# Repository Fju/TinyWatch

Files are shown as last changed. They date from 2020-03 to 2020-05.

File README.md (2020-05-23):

# AVRist-watch

A DIY project that involves an ATmega328p that controlls a small monochrome OLED display powered by a chargable LiPo battery - or in short: a digital wrist watch.

## Features

- **Real Time Clock**: An IC keeps track of the current date and time even if the display and microcontroller is turned off.

- **Li-Po battery management**: The board features a charge controller that allows charging the battery via Micro USB. Another IC protects the battery from over-charging and over-discharging.

- **OLED-Display**: A monochrome 128x64 pixel OLED display is used to show the current time.

- **Energy Efficiency**: After displaying the current time for a couple of seconds the display turns off and the microcontroller enters a sleep mode. This saves battery power.

## Images

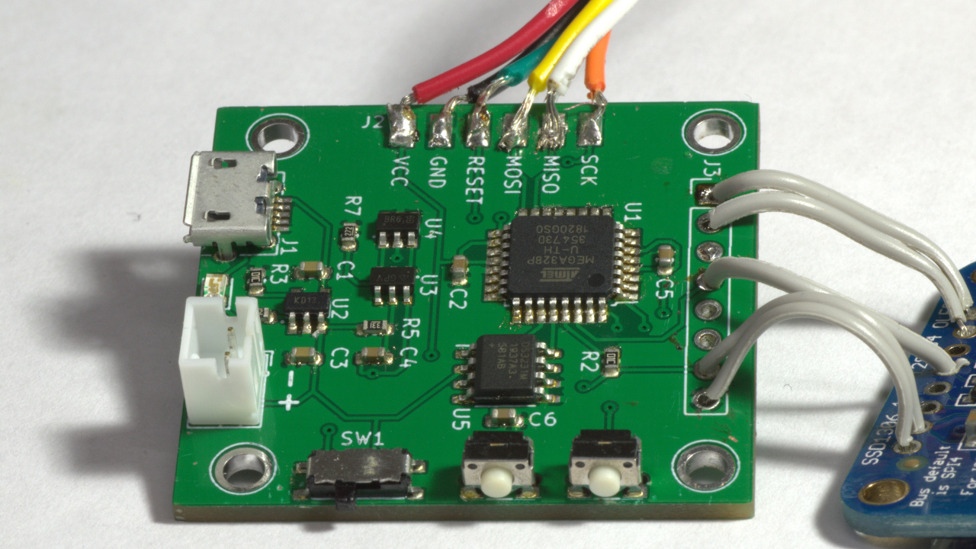
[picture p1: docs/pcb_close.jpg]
PCB up close


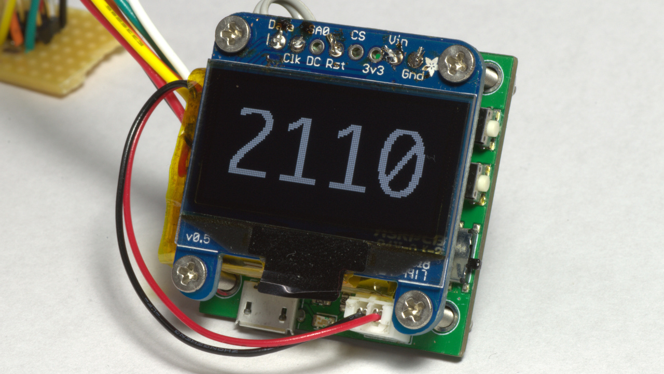
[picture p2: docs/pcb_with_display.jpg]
PCB with OLED display on top


## Schematic

Schematic

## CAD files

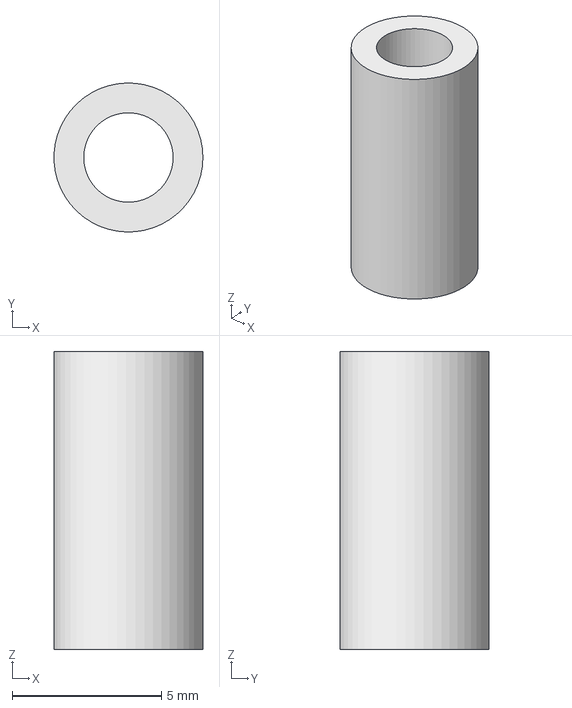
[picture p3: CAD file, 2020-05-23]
parts/mounts.FCStd
5.00 x 5.00 x 10.0 mm

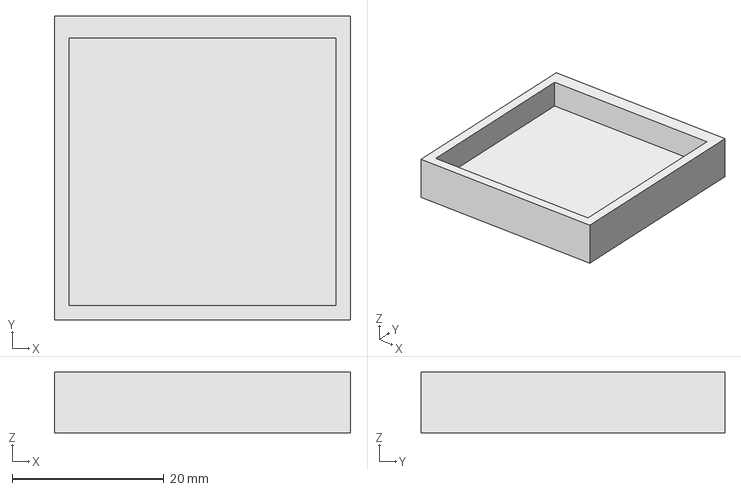
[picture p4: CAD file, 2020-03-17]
parts/case.FCStd
39.0 x 40.0 x 8.00 mm

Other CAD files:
parts/mounts.stl

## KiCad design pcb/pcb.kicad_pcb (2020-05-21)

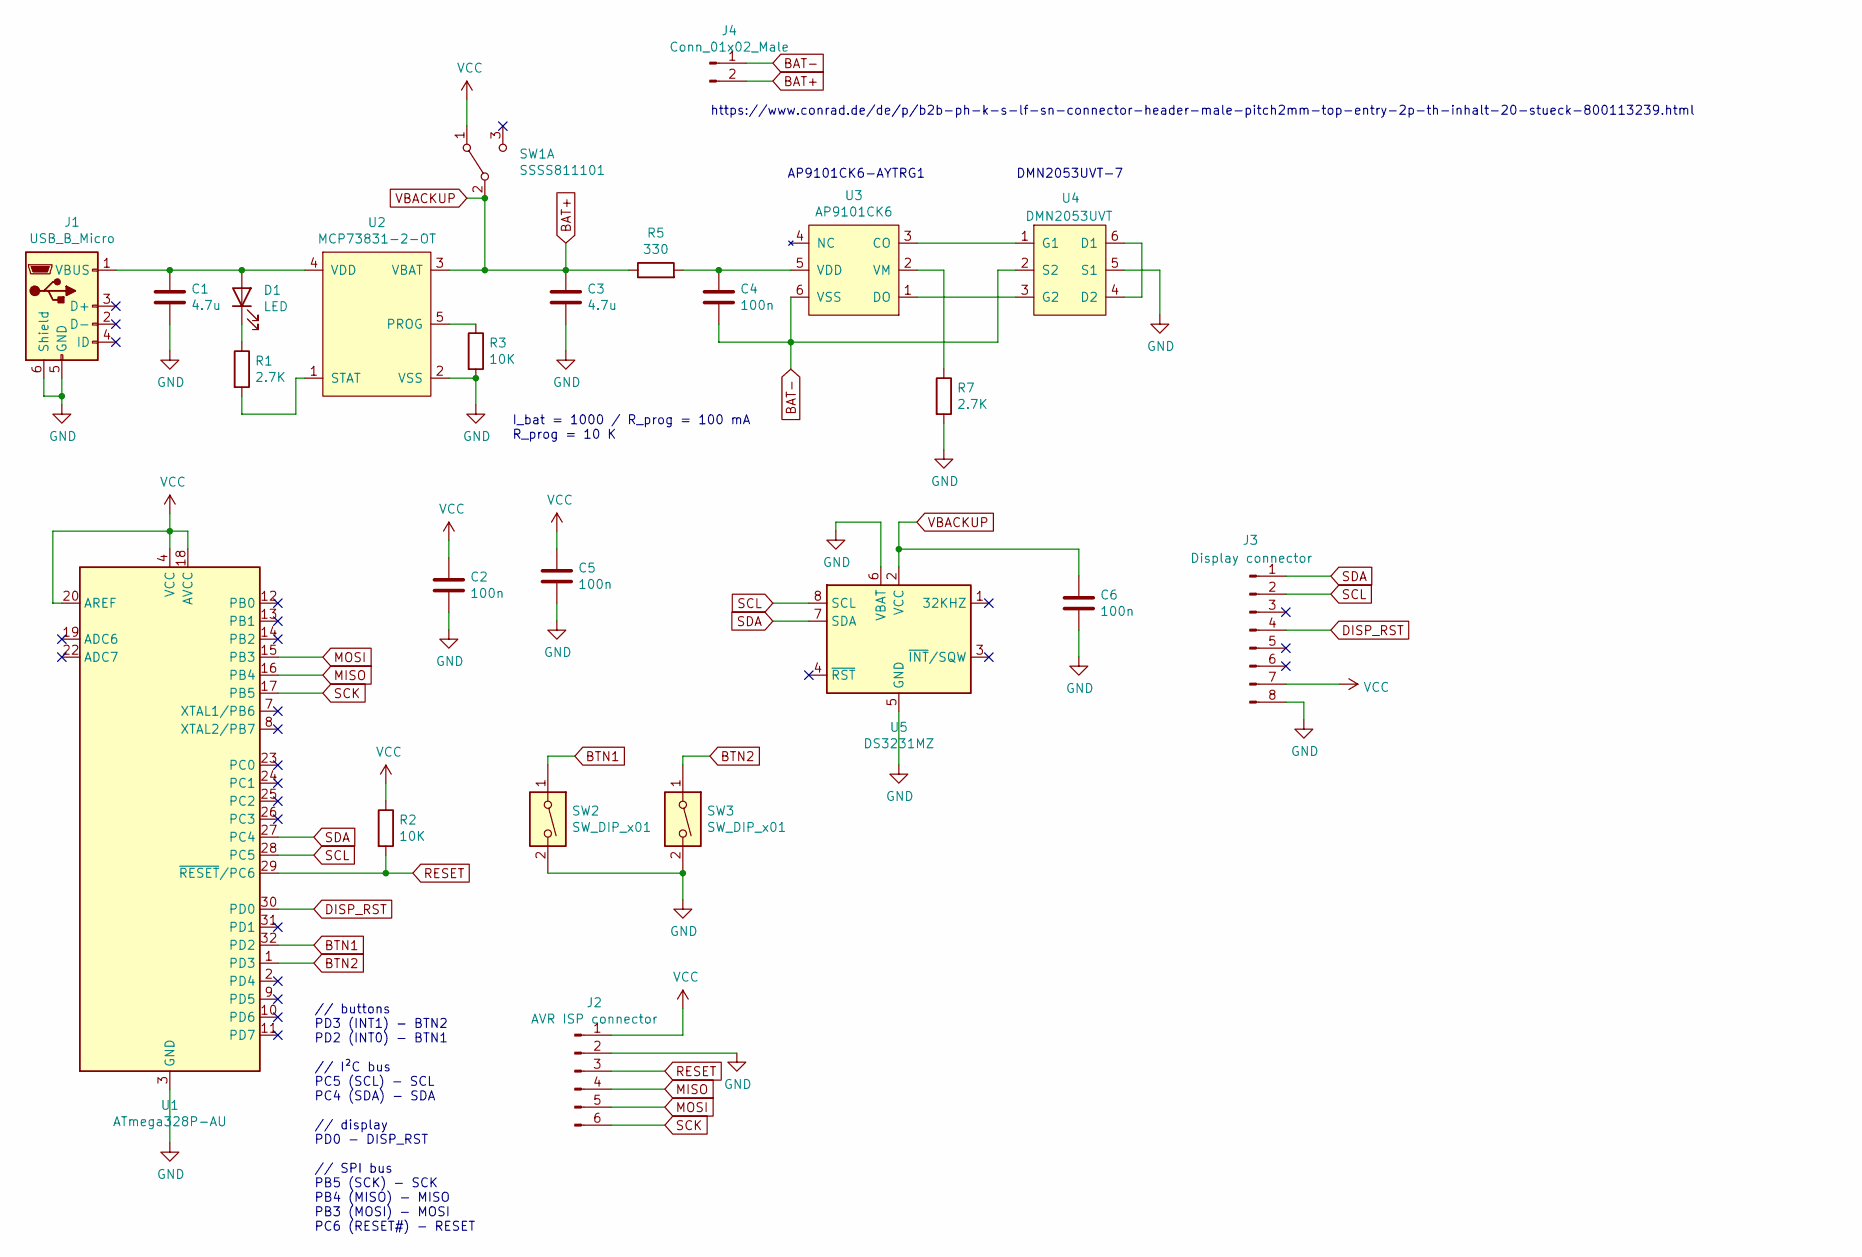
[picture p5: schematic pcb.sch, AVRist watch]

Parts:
C1, C3: 4.7u; C_0603_1608Metric
C2, C4, C5, C6: 100n; C_0603_1608Metric
D1: LED; LED_0805_2012Metric
J1: USB_B_Micro; USB_B_micro
J2: AVR ISP connector; CONN_AVR_ISP_SMD
J3: Display connector; PinHeader_1x08_P2.54mm_Vertical
J4: Conn_01x02_Male; JST_PH_B2B-PH-K_1x02_P2.00mm_Vertical
R1, R7: 2.7K; R_0603_1608Metric
R2, R3: 10K; R_0603_1608Metric
R5: 330; R_0603_1608Metric
SW1: SSSS811101
SW2, SW3: SW_DIP_x01; TL3340_SMT
U1: ATmega328P-AU; TQFP-32_7x7mm_P0.8mm
U2: MCP73831-2-OT; MCP73831_SOT-23
U3: AP9101CK6; AP9101C_SOT-25
U4: DMN2053UVT; DMN2053UVT_TSOT-26
U5: DS3231MZ; SOIC-8_3.9x4.9mm_P1.27mm

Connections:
BAT+: C3.1, C6.1, J4.2, R5.1, SW1.2 (B), U2.3 (VBAT), U5.2 (VCC)
BAT-: C4.2, J4.1, U3.6 (VSS), U4.2 (S2)
BTN1: SW2.1, U1.32 (PD2)
BTN2: SW3.1, U1.1 (PD3)
DISP_RST: J3.4, U1.30 (PD0)
GND: C1.2, C2.2, C3.2, C5.2, C6.2, J1.5 (GND), J1.6 (Shield), J2.2, J3.8, R3.2, R7.2, SW2.2, SW3.2, U1.3 (GND), U1.5 (GND), U1.21 (GND), U2.2 (VSS), U4.5 (S1), U5.5 (GND), U5.6 (VBAT)
MISO: J2.4, U1.16 (PB4)
MOSI: J2.5, U1.15 (PB3)
unnamed: C1.1, D1.2 (A), J1.1 (VBUS), U2.4 (VDD)
unnamed: C4.1, R5.2, U3.5 (VDD)
unnamed: D1.1 (K), R1.1
unnamed: R1.2, U2.1 (STAT)
unnamed: R3.1, U2.5 (PROG)
unnamed: R7.1, U3.2 (VM)
unnamed: U3.1 (DO), U4.3 (G2)
unnamed: U3.3 (CO), U4.1 (G1)
unnamed: U4.4 (D2), U4.6 (D1)
RESET: J2.3, R2.2, U1.29 (~RESET~/PC6)
SCK: J2.6, U1.17 (PB5)
SCL: J3.2, U1.28 (PC5), U5.8 (SCL)
SDA: J3.1, U1.27 (PC4), U5.7 (SDA)
VCC: C2.1, C5.1, J2.1, J3.7, R2.1, SW1.1 (A), U1.4 (VCC), U1.6 (VCC), U1.18 (AVCC), U1.20 (AREF)

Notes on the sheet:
I_bat = 1000 / R_prog = 100 mA R_prog = 10 K
// buttons PD3 (INT1) - BTN2 PD2 (INT0) - BTN1 // I²C bus PC5 (SCL) - SCL PC4 (SDA) - SDA // display PD0 - DISP_RST // SPI bus PB5 (SCK) - SCK PB4 (MISO) - MISO PB3 (MOSI) - MOSI PC6 (RESET#) - RESET
AP9101CK6-AYTRG1
DMN2053UVT-7
https://www.conrad.de/de/p/b2b-ph-k-s-lf-sn-connector-header-male-pitch2mm-top-entry-2p-th-inhalt-20-stueck-800113239.html

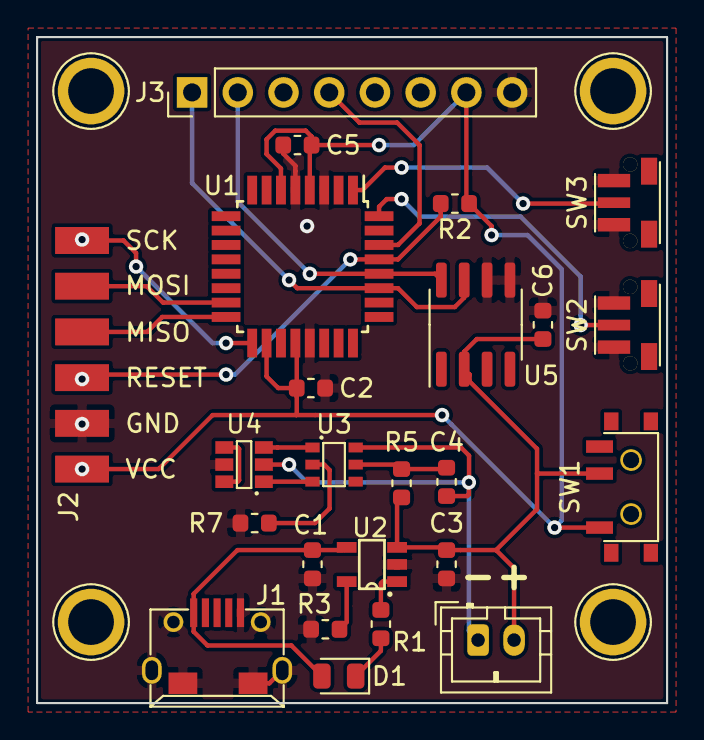
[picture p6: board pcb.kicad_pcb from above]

Board: 2 copper layers, 35.0 x 37.0 mm, 24 parts (0 on the bottom side), 22 nets.

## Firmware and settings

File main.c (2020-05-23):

#include <avr/io.h>
#include <avr/power.h>
#include <avr/sleep.h>
#include <avr/interrupt.h>

#include "screen.h"
#include "i2c_master.h"
#include "fonts.h"
#include "clock.h"

#include <util/delay.h>

enum state_t {
	S_TIME,			// display time
	S_MENU_TIME,	// set time (hours and minutes)
	S_MENU_DATE,	// set date (day and month)
	S_MENU_YEAR		// set year
};

int main() {
	// set all I/O to outputs to save some energy, except the following:
	// INT0 (PD2), INT1 (PD3), SCL (PC5), SDA (PC4)
    DDRB = 0xFF;
    DDRC |= ~((1 << PC5) | (1 << PC4));
    DDRD |= ~((1 << PD2) | (1 << PD3));

	// active pull-up 
	PORTD |= (1 << PD2) | (1 << PD3);

	// turn off ADC
	ACSR = 0x80;

	// disable all components except TWI
	PRR |= ~(1 << PRTWI);

	// allocate memory for screen
	if (screen_begin()) while(1);

	// set interrupt enabled
	sei();


	enum state_t state;

	uint8_t btn1_state = 0;
	uint8_t btn2_state = 0;

	uint8_t hours = 0;
	uint8_t minutes = 0;
	uint8_t day = 0;
	uint8_t month = 0;
	uint8_t year = 0;

	uint8_t digit_selection = 0;

	uint8_t timeout = 0;

	// wake up/sleep loop
	while(1) {
		// two-wire interface needs to be resetted
		i2c_init();

		// turn on screen
		screen_on();

		state = S_TIME;
		timeout = 0;

		// display loop
		while (1) {
			// update state of button 1
			if (PIND & (1 << PD2)) {
				btn1_state = 0;
			} else if (btn1_state < 32) {
			   	++btn1_state;
			}
			
			// update state of button 2 
			if (PIND & (1 << PD3)) {
				btn2_state = 0;
			} else if (btn2_state < 32) {
				++btn2_state;
			}

			switch (state) {
				case S_TIME:
					// obtain time from RTC
					minutes = get_minutes();
					hours = get_hours();

					// display time
					screen_draw_character(numbers_bitmap, hours / 10, NUMBERS_CHAR_HEIGHT, NUMBERS_CHAR_WIDTH, 4, 15, 0);
					screen_draw_character(numbers_bitmap, hours % 10, NUMBERS_CHAR_HEIGHT, NUMBERS_CHAR_WIDTH, 28, 15, 0);
					screen_draw_character(numbers_bitmap, 10, NUMBERS_CHAR_HEIGHT, NUMBERS_CHAR_WIDTH, 52, 15, 0);
					screen_draw_character(numbers_bitmap, minutes / 10, NUMBERS_CHAR_HEIGHT, NUMBERS_CHAR_WIDTH, 78, 15, 0);
					screen_draw_character(numbers_bitmap, minutes % 10, NUMBERS_CHAR_HEIGHT, NUMBERS_CHAR_WIDTH, 102, 15, 0);

					++timeout;

					// detect long press
					if (btn1_state > 20) {
						// switch state
						state = S_MENU_TIME;
						screen_clear();
						// don't timeout when not in state S_TIME
						timeout = 0;
						// get day, month and year once
						day = get_date();
						month = get_month();
						year = get_year();
					}
					break;
				case S_MENU_TIME:
					// draw header ("hh:mm")
					screen_draw_character(character_bitmap, 4, TEXT_CHAR_HEIGHT, TEXT_CHAR_WIDTH, 24, 1, 0);
					screen_draw_character(character_bitmap, 4, TEXT_CHAR_HEIGHT, TEXT_CHAR_WIDTH, 40, 1, 0);
					screen_draw_character(character_bitmap, 5, TEXT_CHAR_HEIGHT, TEXT_CHAR_WIDTH, 56, 1, 0);
					screen_draw_character(character_bitmap, 3, TEXT_CHAR_HEIGHT, TEXT_CHAR_WIDTH, 72, 1, 0);
					screen_draw_character(character_bitmap, 3, TEXT_CHAR_HEIGHT, TEXT_CHAR_WIDTH, 88, 1, 0);

					screen_draw_character(numbers_bitmap, hours / 10, NUMBERS_CHAR_HEIGHT, NUMBERS_CHAR_WIDTH, 4, 30, digit_selection == 0 ? 0xFF : 0);
					screen_draw_character(numbers_bitmap, hours % 10, NUMBERS_CHAR_HEIGHT, NUMBERS_CHAR_WIDTH, 28, 30, digit_selection == 1 ? 0xFF : 0);
					screen_draw_character(numbers_bitmap, 10, NUMBERS_CHAR_HEIGHT, NUMBERS_CHAR_WIDTH, 52, 30, 0);
					screen_draw_character(numbers_bitmap, minutes / 10, NUMBERS_CHAR_HEIGHT, NUMBERS_CHAR_WIDTH, 78, 30, digit_selection == 2 ? 0xFF : 0);
					screen_draw_character(numbers_bitmap, minutes % 10, NUMBERS_CHAR_HEIGHT, NUMBERS_CHAR_WIDTH, 102, 30, digit_selection == 3 ? 0xFF : 0);

					if (btn1_state == 1) {
						++digit_selection;

						if (digit_selection == 4) {
							// update time
							set_hours(hours);
							set_minutes(minutes);

							// switch state
							state = S_MENU_DATE;
							screen_clear();
							digit_selection = 0;
						}
					}

					if (btn2_state == 1) {
						if (digit_selection == 0) hours += 10;
						else if (digit_selection == 1) hours += 1;
						else if (digit_selection == 2) minutes += 10;
						else if (digit_selection == 3) minutes += 1;

						if (hours > 23) hours = 0;
						if (minutes > 59) minutes = 0;
					}
					break;
				case S_MENU_DATE:
					// draw header ("DD MM")
					screen_draw_character(character_bitmap, 1, TEXT_CHAR_HEIGHT, TEXT_CHAR_WIDTH, 24, 1, 0);
					screen_draw_character(character_bitmap, 1, TEXT_CHAR_HEIGHT, TEXT_CHAR_WIDTH, 40, 1, 0);
					screen_draw_character(character_bitmap, 2, TEXT_CHAR_HEIGHT, TEXT_CHAR_WIDTH, 72, 1, 0);
					screen_draw_character(character_bitmap, 2, TEXT_CHAR_HEIGHT, TEXT_CHAR_WIDTH, 88, 1, 0);

					screen_draw_character(numbers_bitmap, day / 10, NUMBERS_CHAR_HEIGHT, NUMBERS_CHAR_WIDTH, 4, 30, digit_selection == 0 ? 0xFF : 0);
					screen_draw_character(numbers_bitmap, day % 10, NUMBERS_CHAR_HEIGHT, NUMBERS_CHAR_WIDTH, 28, 30, digit_selection == 1 ? 0xFF : 0);

					screen_draw_character(numbers_bitmap, month / 10, NUMBERS_CHAR_HEIGHT, NUMBERS_CHAR_WIDTH, 78, 30, digit_selection == 2 ? 0xFF : 0);
					screen_draw_character(numbers_bitmap, month % 10, NUMBERS_CHAR_HEIGHT, NUMBERS_CHAR_WIDTH, 102, 30, digit_selection == 3 ? 0xFF : 0);

					if (btn1_state == 1) {
						++digit_selection;

						if (digit_selection == 4) {
							// update date
							set_date(day);
							set_month(month);

							// switch state
							state = S_MENU_YEAR;
							screen_clear();
							digit_selection = 0;
						}
					}

					if (btn2_state == 1) {
						if (digit_selection == 0) day += 10;
						else if (digit_selection == 1) day += 1;
						else if (digit_selection == 2) month += 10;
						else if (digit_selection == 3) month += 1;

						if (day > 31) day = 1;
						if (month > 12) month = 1;
					}
					break;
				case S_MENU_YEAR:
					// draw header ("YYYY")
					screen_draw_character(character_bitmap, 0, TEXT_CHAR_HEIGHT, TEXT_CHAR_WIDTH, 32, 1, 0);
					screen_draw_character(character_bitmap, 0, TEXT_CHAR_HEIGHT, TEXT_CHAR_WIDTH, 48, 1, 0);
					screen_draw_character(character_bitmap, 0, TEXT_CHAR_HEIGHT, TEXT_CHAR_WIDTH, 64, 1, 0);
					screen_draw_character(character_bitmap, 0, TEXT_CHAR_HEIGHT, TEXT_CHAR_WIDTH, 80, 1, 0);
					
					// draw digits of year
					screen_draw_character(numbers_bitmap, 2, NUMBERS_CHAR_HEIGHT, NUMBERS_CHAR_WIDTH, 16, 30, 0);
					screen_draw_character(numbers_bitmap, 0, NUMBERS_CHAR_HEIGHT, NUMBERS_CHAR_WIDTH, 40, 30, 0);
					screen_draw_character(numbers_bitmap, year / 10, NUMBERS_CHAR_HEIGHT, NUMBERS_CHAR_WIDTH, 64, 30, digit_selection == 0 ? 0xFF : 0);
					screen_draw_character(numbers_bitmap, year % 10, NUMBERS_CHAR_HEIGHT, NUMBERS_CHAR_WIDTH, 86, 30, digit_selection == 1 ? 0xFF : 0);
					
					if (btn1_state == 1) {
						++digit_selection;

						if (digit_selection == 2) {
							// update year
							set_year(year);

							// switch state
							state = S_TIME;
							screen_clear();
							digit_selection = 0;
						}
					}
				
					if (btn2_state == 1) {
						if (digit_selection == 0) year += 10;
						else if (digit_selection == 1) year += 1;

						if (year > 99) year = 0;
					}
					break;
			}

			// refresh screen
			screen_display();
			_delay_ms(60);

			if (timeout > 50) {
				// leave loop, go to sleep
				break;
			}
		}	

		// turn off screen
		screen_off();

		// enable INT0 and INT1
		EIMSK |= (1 << INT1) | (1 << INT0);

		// sleep in power down mode
		set_sleep_mode(SLEEP_MODE_PWR_DOWN);
        sleep_mode();

		// wake up here, disable interrupts
		EIMSK &= ~((1 << INT1) | (1 << INT0));
	}
}

// these interrupt routines MUST exists but can be empty
ISR(INT0_vect) {
}

ISR(INT1_vect) {
}

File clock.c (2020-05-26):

#include "clock.h"

uint32_t get_time() {
	// combine all time values to a 32-bit number
	uint32_t time = get_hours() << 12;
	time |= get_minutes() << 6;
	time |= get_seconds();

	return time;
}

uint8_t get_hours() {
	// read from hours register (address = 0x02)
	// bits: [ MSB ][   6   ][     5    ][     4    ][ 3 ][ 2 ][ 1 ][ 0 ]
	//       [  0  ][ 24/12 ][   AM/PM  ][ 10 hours ][       hours      ]
	//                       [ 20 hours ]
	// If Bit 6 is set the hour data is encoded in the 12 mode, which means
	// that Bit 5 indicates AM (not set) or PM (set). In 24 hour mode
	// (Bit 6 not set) Bit 5 stands for 20 hours (if set).
	uint8_t data;
	i2c_readReg(CLOCK_ADDR, CLOCK_HOURS_REG, &data, 1);

	uint8_t hours = data & 0x0F;

	if (data & 0x10) hours += 10;

	if (data & 0x40) {
		// 12 hour mode
		hours = hours % 12;
		// PM flag set
		if (data & 0x20) hours += 12;
	} else {
		// 24 hour mode
		if (data & 0x20) hours += 20;
	}

	return hours;
}

void set_hours(uint8_t hours) {
	// 12 hour mode flag already set
	uint8_t data = 0x40;

	// set PM flag
	if (hours >= 12) data |= 0x20;

	// convert to 12 hour format (12 PM = 12:00, 12 AM = 0:00)
	hours = hours % 12;
	if (hours == 0) hours = 12;

	data |= (hours % 10) & 0x0F;
	if (hours >= 10) data |= 0x10;

	i2c_writeReg(CLOCK_ADDR, CLOCK_HOURS_REG, &data, 1);
}

uint8_t get_minutes() {
	// read from minutes register (address = 0x01)
	// bits: [ MSB ][ 6 ][ 5 ][ 4 ][ 3 ][ 2 ][ 1 ][ LSB ]
	//       [  0  ][ 10 minutes  ][       minutes      ]
	uint8_t data;
	i2c_readReg(CLOCK_ADDR, CLOCK_MINUTES_REG, &data, 1);

	uint8_t minutes = data & 0x0F;
	minutes += ((data & 0x70) >> 4) * 10;

	return minutes;
}

void set_minutes(uint8_t minutes) {
	uint8_t data = 0;
	
	data |= (minutes % 10) & 0x0F;
	data |= ((minutes / 10) << 4) & 0x70;
	i2c_writeReg(CLOCK_ADDR, CLOCK_MINUTES_REG, &data, 1);
}

uint8_t get_seconds() {
	// read from seconds register (address = 0x00)
	// bits: [ MSB ][ 6 ][ 5 ][ 4 ][ 3 ][ 2 ][ 1 ][ LSB ]
	//       [  0  ][ 10 seconds  ][       seconds      ]
	uint8_t data;
	i2c_readReg(CLOCK_ADDR, CLOCK_SECONDS_REG, &data, 1);

	uint8_t seconds = data & 0x0F;
	seconds += ((data & 0x70) >> 4) * 10;

	return seconds;
}

void set_seconds(uint8_t seconds) {
	uint8_t data = 0;

	data |= (seconds % 10) & 0x0F;
	data |= ((seconds / 10) << 4) & 0x70;

	i2c_writeReg(CLOCK_ADDR, CLOCK_SECONDS_REG, &data, 1);
}

uint8_t get_date() {
	// read from date register (address = 0x04)
	// value range: 01 - 31
	// bits: [ MSB ][ 6 ][  5 ][ 4 ][ 3 ][ 2 ][ 1 ][ LSB ]
	//       [  0  ][ 0 ][ 10 date ][        date        ]
	uint8_t data;
	i2c_readReg(CLOCK_ADDR, CLOCK_DATE_REG, &data, 1);

	uint8_t date = data & 0x0F;
	date += ((data & 0x30) >> 4) * 10;

	return date;
}

void set_date(uint8_t date) {
	// write to date register (address = 0x04)
	// bits: [ MSB ][ 6 ][  5 ][ 4 ][ 3 ][ 2 ][ 1 ][ LSB ]
	//       [  0  ][ 0 ][ 10 date ][        date        ]
	uint8_t data = 0;

	data |= (date % 10) & 0x0F;
	data |= ((date / 10) << 4) & 0x30;

	i2c_writeReg(CLOCK_ADDR, CLOCK_DATE_REG, &data, 1);
}

uint8_t get_month() {
	// read from month register (address = 0x05)
	// value range: 01 - 12
	// bits: [    MSB    ][ 6 ][ 5 ][     4    ][ 3 ][ 2 ][ 1 ][ LSB ]
	//       [  century  ][ 0 ][ 0 ][ 10 month ][       month        ]
	
	uint8_t data = 0;
	i2c_readReg(CLOCK_ADDR, CLOCK_MONTH_REG, &data, 1);

	uint8_t month = data & 0x0F;
	month += ((data & 0x10) >> 4) * 10;

	return month;
}

void set_month(uint8_t month) {
	// write to month register (address = 0x05)
	// bits: [    MSB    ][ 6 ][ 5 ][     4    ][ 3 ][ 2 ][ 1 ][ LSB ]
	//       [  century  ][ 0 ][ 0 ][ 10 month ][       month        ]
	uint8_t data = 0;

	data |= (month % 10) & 0x0F;
	data |= ((month / 10) << 4) & 0x10;
	// set century to 1
	data |= 0x80;

	i2c_writeReg(CLOCK_ADDR, CLOCK_MONTH_REG, &data, 1);
}


uint8_t get_year() {
	// read from year register (address = 0x06)
	// value range: 00 - 99
	// bits: [ MSB ][ 6 ][ 5 ][ 4 ][ 3 ][ 2 ][ 1 ][ LSB ]
	//       [       10 year      ][        year        ]
	
	uint8_t data = 0;
	i2c_readReg(CLOCK_ADDR, CLOCK_YEAR_REG, &data, 1);

	uint8_t year = data & 0x0F;
	year += ((data & 0xF0) >> 4) * 10;

	return year;
}

void set_year(uint8_t year) {
	// write to year register (address = 0x06)
	// bits: [ MSB ][ 6 ][ 5 ][ 4 ][ 3 ][ 2 ][ 1 ][ LSB ]
	//       [       10 year      ][        year        ]
	uint8_t data = 0;

	data |= (year % 10) & 0x0F;
	data |= ((year / 10) << 4) & 0xF0;

	i2c_writeReg(CLOCK_ADDR, CLOCK_YEAR_REG, &data, 1);
}

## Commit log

2018-11-17 Library for custom parts
    Eagle hasn't got the BQ32002 and the MCP73831/2 required for this project. So I created a library that includes these parts. All dimensions and pin names were adopted from the official datasheets.
2018-11-17 Corrected unit for custom parts' footprints
    I messed up the units when I created the library for the custom parts (used milli-inch instead of millimeters).
2018-11-19 Added laying capacitor and C++ source code
    The code files originate from adafruits SSD1306 library and were modified for the use of the ATTiny84. I will add more details about this in the next commit.
2018-11-21 Added .ino for Arduino IDE
2020-02-18 Added schematic to `docs`
2020-03-04 Added fuses configuration and explanation
2020-03-08 Designed schematic using KiCAD
    [pcb.kicad_pcb, pcb.sch]
2020-03-08 Improved schematic
    [pcb.sch]
2020-03-16 Updated schematic and added gitignore for KiCAD files
    [Adafruit_1.3_128x64_OLED.brd, pcb.sch]
2020-03-17 Added datasheets and push button footprint
    [case.FCStd, pcb.sch]
2020-03-17 Updated footprints and schematic
    [pcb.kicad_pcb, pcb.sch]
2020-03-29 Finalized PCB layout
    [pcb.kicad_pcb, pcb.sch]
2020-04-25 Finalized schematic and PCB layout
    [pcb.kicad_pcb, pcb.sch]
2020-05-02 Changed TL3340 footprint
    [pcb.kicad_pcb, pcb.sch]
2020-05-21 Pull-up for INT0 and INT1, display reset pin
    [Adafruit_1.3_128x64_OLED.brd]
2020-05-21 Fixed MISO/MOSI mistake in PCB and schematic
    [pcb.kicad_pcb, pcb.sch]
2020-05-21 Added schematic to README
    [pcb.sch]
2020-05-23 Added two pictures and 3D printed mounts
    [mounts.FCStd, mounts.stl]
